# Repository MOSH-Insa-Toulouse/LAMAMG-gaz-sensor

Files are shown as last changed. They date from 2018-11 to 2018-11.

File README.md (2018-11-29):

# LAMAMG-gaz-sensor

> A Smart Gaz Sensor that just works.

[][node-red-url]
[][node-red-dashboard-url]
[][node-red-ttn-url]
[][arduino-ttn-url]

The result of our project can be seen on the following picture, which is a screenshot of our application's dashboard.

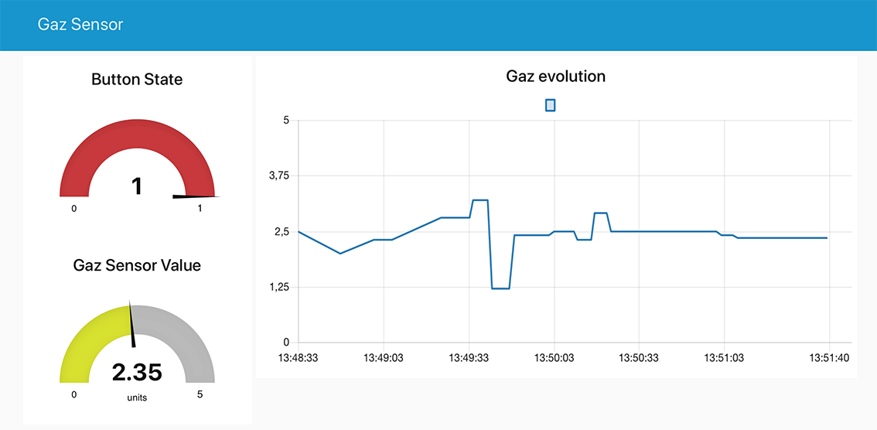
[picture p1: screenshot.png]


Our application is simple:
- we collect data through a gaz sensor connected to an Arduino board
- then, we send it to a NodeRed serving using TTN and LoRa
- once the data is received by the server, the dashboard is updated
- the values are displayed separately (two gauges for the sensor & the button state values, one chart for the evolution of the sensor value)

As of now, the button is purely decorative (it once served to send data when at '1').   

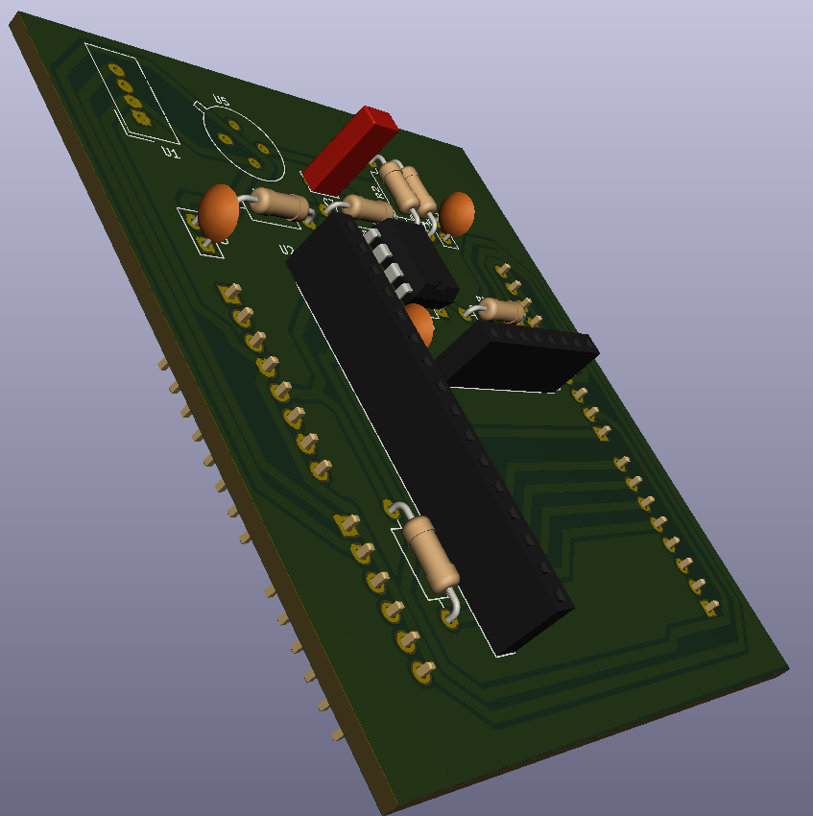
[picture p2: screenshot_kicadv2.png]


We designed our own Arduino shield using the KiCad software. It directly connects to the Arduino board used (101). 
On it, you can add the following devices:
- a Grove LCD screen (http://wiki.seeedstudio.com/Grove-LCD_RGB_Backlight)
- a Grove gaz sensor (http://wiki.seeedstudio.com/Grove-Gas_Sensor)
- our homemade gaz sensor (with an integrated AOP)
- the RN2483 LoRa transceiver module and its board (https://www.microchip.com/wwwproducts/en/RN2483) 

## Installation

OS X & Linux:

```bash
sudo apt install nodejs npm
npm install node-red node-red-ttn node-red-dashboard
cp NodeRED/flows.json ~/.node-red/flows.json
node-red &
```

Then the Dashboard will be visible on http://localhost:1880/ui, and the admin page
will be available on http://localhost:1880.

## Usage example

Power up the Arduino next to a LoRa Gateway which is using The Things Network.
Then connect to http://localhost:1880/ui on the device running Node-Red, and watch
the gauges and the graphs updated in real-time.

## Dependencies

* Node-RED
    * node-red
    * node-red-dashboard
    * node-red-contrib-ttn
* TTN - The Things Network Account
* Arduino
    * Arduino Compiler
    * The Things Network Library
    * Software Serial Library

## Development setup

### NodeRED
Follow the Instllation section, and visit the http://localhost:1880/ with your
favorite browser. You can here change the flows linked to the Dashboard.
Please update the default NodeRED flow to `~/path/to/directory/NodeRED/flows.json`
into the `~/.node-red/settings.json` file before modifying the flows.

### KiCad
The PCB has been designed on KiCad. To contribute to it, you should install it on
[here](http://kicad-pcb.org/download/).
You will then find the KiCad project into the `Kicad/shield` directory.

### Arduino code
The Arduino Code has been developped on _Arduino IDE_ which can be
downloaded [here](https://www.arduino.cc/en/Main/Software). You may need
to fix the dependencies you'll find in the Dependencies' section.
You can easily find them into the package manager of the IDE.

## Contributors
 
 | Name           | Contact                        |
 |----------------|--------------------------------|
 | Maxime Grac    | grac@etud.insa-toulouse.fr     |
 | Lucas Audibert | l_audibe@etud.insa-toulouse.fr |
 | Adrien Marty   | a_marty@etud.insa-toulouse.fr  |

Distributed under the MIT license. See ``LICENSE`` for more information.

## Contributing

1. Fork it (https://github.com/MOSH-Insa-Toulouse/LAMAMG-gaz-sensor.git)
2. Create your feature branch (`git checkout -b feature/fooBar`)
3. Commit your changes (`git commit -am 'Add some fooBar'`)
4. Push to the branch (`git push origin feature/fooBar`)
5. Create a new Pull Request

<!-- Markdown link & img dfn's -->
[node-red-image]: https://img.shields.io/badge/node--red-v0.19.5-orange.svg
[node-red-url]: https://nodered.org
[node-red-dashboard-image]: https://img.shields.io/badge/node--red--dashboard-v2.9.8-orange.svg
[node-red-dashboard-url]: https://github.com/node-red/node-red-dashboard
[node-red-ttn-image]: https://img.shields.io/badge/node--red--ttn-v2.0.4-orange.svg
[node-red-ttn-url]: https://www.npmjs.com/package/node-red-contrib-ttn
[arduino-ttn-image]: https://img.shields.io/badge/TTN_Arduino-v2.5.13-orange.svg
[arduino-ttn-url]: https://github.com/TheThingsNetwork/arduino-device-lib

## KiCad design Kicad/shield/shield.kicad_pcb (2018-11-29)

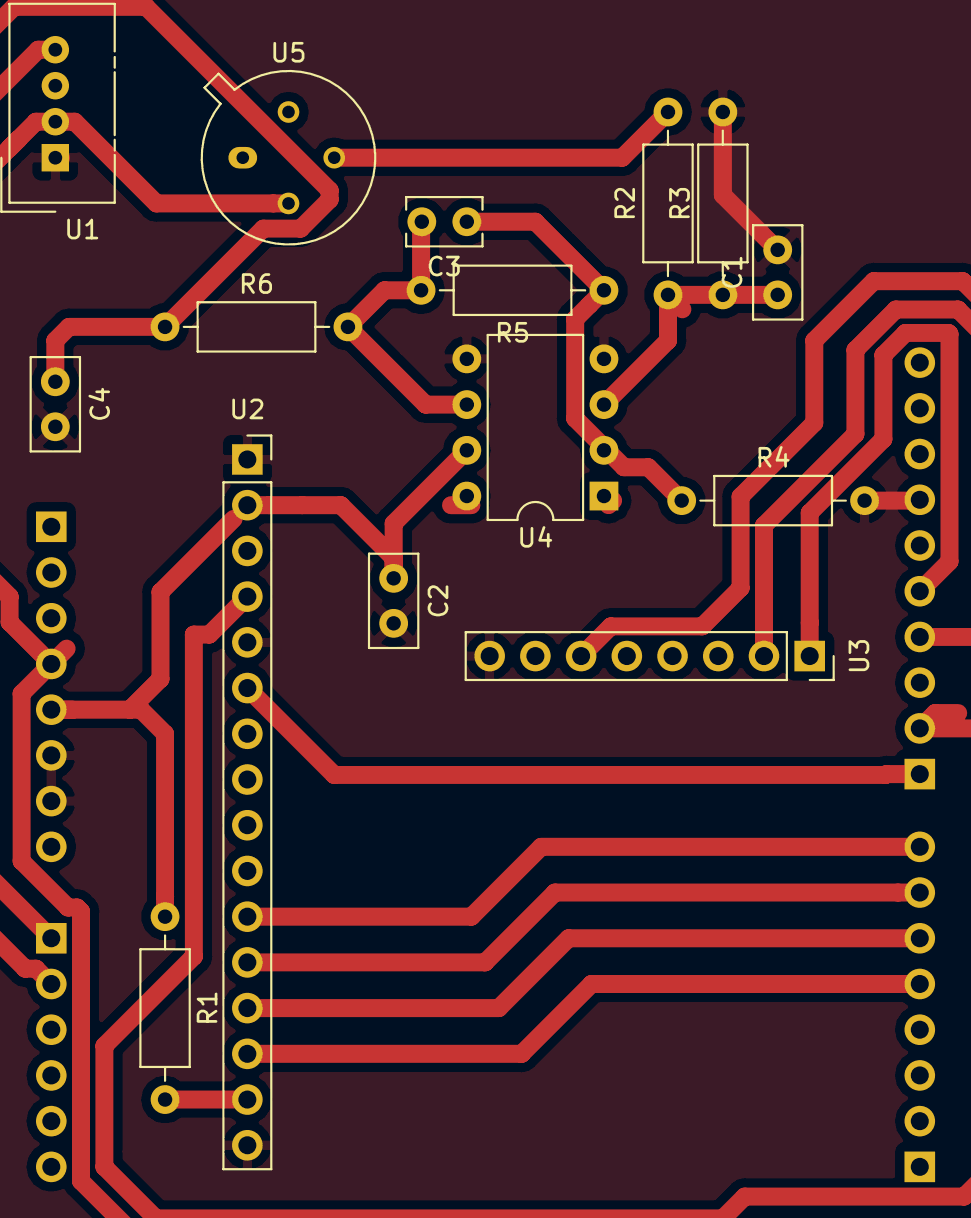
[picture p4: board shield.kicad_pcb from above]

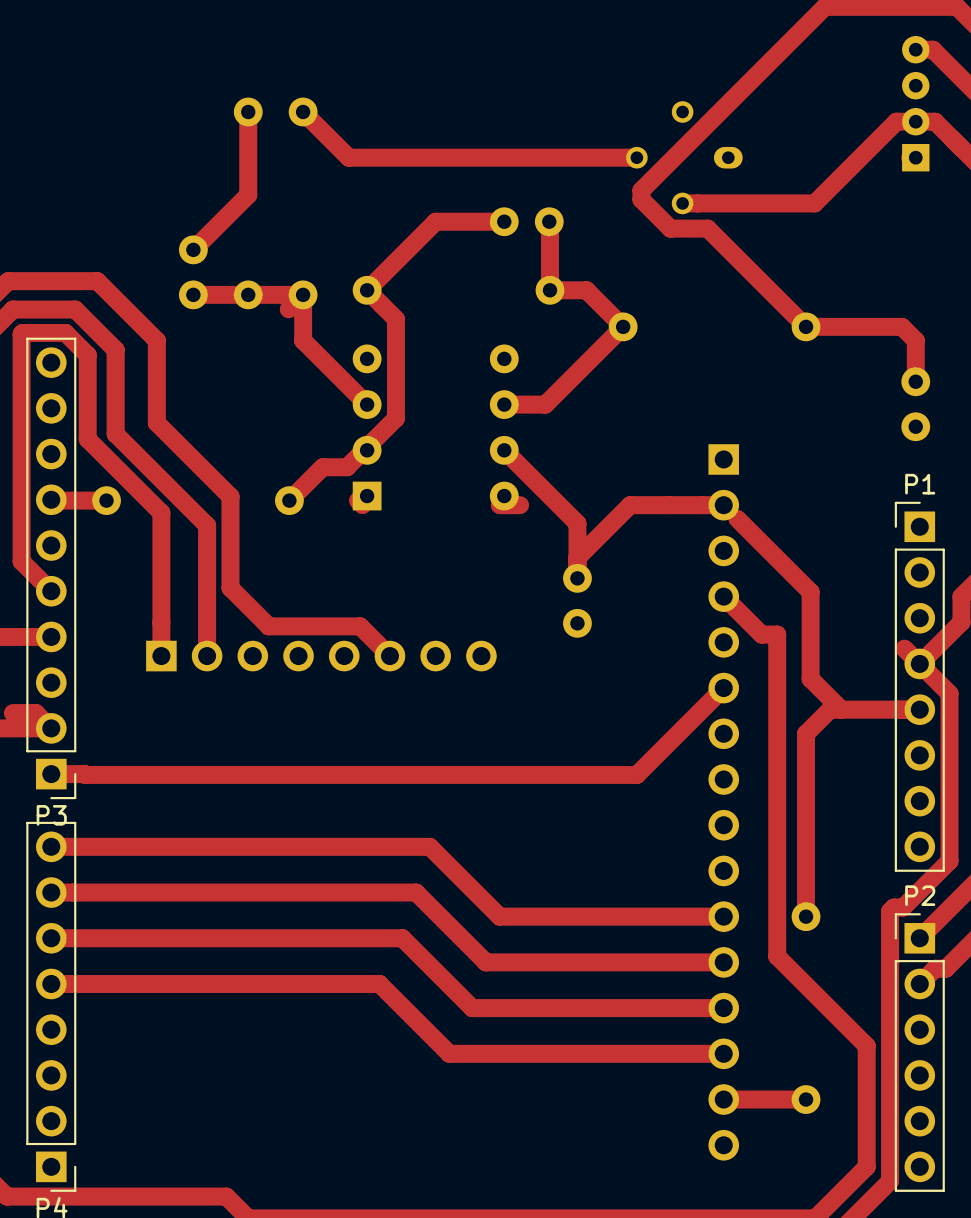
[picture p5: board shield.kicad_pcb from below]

Board: 2 copper layers, 19 parts (4 on the bottom side), 18 nets.

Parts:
C1, C2, C4: C; C_Disc_D5.0mm_W2.5mm_P2.50mm
C3: C; C_Rect_L4.0mm_W2.5mm_P2.50mm
P1, P4: CONN_01X08; PinHeader_1x08_P2.54mm_Vertical
P2: CONN_01X06; PinHeader_1x06_P2.54mm_Vertical
P3: CONN_01X10; PinHeader_1x10_P2.54mm_Vertical
R1, R2, R3, R4, R5, R6: R; R_Axial_DIN0207_L6.3mm_D2.5mm_P10.16mm_Horizontal
U1: gaz_sensor; NS-Tech_Grove_1x04_P2mm_Vertical
U2: LCD_screen; PinSocket_1x16_P2.54mm_Vertical
U3: RN2483A; PinSocket_1x08_P2.54mm_Vertical
U4: LT1050; DIP-8_W7.62mm
U5: Gaz_Sensor; TO-5-4

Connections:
+3V3: P1.4, U1.2, U3.6, U5.2
+5V: C2.1, P1.5, R1.1, U2.2, U4.7
/#D5: P4.6, U2.13
/#D6: P4.7, U2.12
/#D9: P3.2, U2.4
/#D11: P3.4, U3.2
/A0: P2.1, U1.4
/A1: C4.1, P2.2, R6.1
/D4: P4.5, U2.14
/D7: P4.8, U2.11
/D8: P3.1, U2.6
/D12: P3.5, U3.1
/Isens: R2.2, U5.3
GND: C1.2, C2.2, C4.2, P1.6, P1.7, P3.7, R3.2, R4.2, U1.1, U2.1, U2.5, U2.16, U3.8, U4.4, U4.5
unnamed: C1.1, R2.1, R3.1, U4.3
unnamed: C3.1, R4.1, R5.1, U4.2
unnamed: C3.2, R5.2, R6.2, U4.6
unnamed: R1.2, U2.15

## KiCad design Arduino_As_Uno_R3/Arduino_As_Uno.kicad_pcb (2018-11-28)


Board: 2 copper layers, 68.6 x 53.3 mm, 8 parts (0 on the bottom side), 3 nets, no tracks yet.

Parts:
P1: Power; Socket_Strip_Arduino_1x08
P2: Analog; Socket_Strip_Arduino_1x06
P3: Digital; Socket_Strip_Arduino_1x10
P4: Digital; Socket_Strip_Arduino_1x08
P5, P6, P7, P8: CONN_01X01; Arduino_1pin

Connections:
/A4(SDA): P2.5, P3.2
/A5(SCL): P2.6, P3.1
GND: P1.6, P1.7, P3.4

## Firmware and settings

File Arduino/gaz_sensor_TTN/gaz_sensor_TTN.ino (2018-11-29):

#include <LiquidCrystal.h>
#include <TheThingsNetwork.h>
#include <SoftwareSerial.h>

// Creating a software serial
SoftwareSerial loraSerial(8,9);
#define debugSerial Serial

// Variables' declaration
float sensor_volt = 0;
int LED = 13;
volatile byte state = LOW;
LiquidCrystal myScreen(12,11,7,6,5,4); // creating the screen object

// Data needed to connect to the TTN 
const char *devAddr = "26011078";
const char *nwkSKey = "E63AE401DD3BA8C23DA9670B93455FF3";
const char *appSKey = "B28065B3C01B31621D5D0DED68B16511";

TheThingsNetwork ttn(loraSerial, debugSerial, TTN_FP_EU868);

void setup() {
  // Setting up the serial ports
  loraSerial.begin(57600);
  debugSerial.begin(9600);

  // Asking for the TTN status
  debugSerial.println("-- STATUS");
  ttn.showStatus();

  // Configuring the TTN
  debugSerial.println("-- PERSONALIZE");
  ttn.personalize(devAddr, nwkSKey, appSKey);
  ttn.personalize();
  debugSerial.println("-- PERSONALIZED");

  // Configuring the LED
  pinMode(LED,OUTPUT);
  pinMode(2,INPUT_PULLUP);
  digitalWrite(LED, LOW);

  // Initializing the LCD screen
  myScreen.begin(16,2);
  myScreen.clear();
  myScreen.print("Gaz Sensor");
  myScreen.setCursor(0, 1);

  // Creating a payload to be sent to the TTN
  byte payload[1];
  payload[0] = (digitalRead(2) == HIGH) ? 1 : 0;
  ttn.sendBytes(payload, sizeof(payload));
}

void loop() {
  // Displaying the analog value of the sensor on the LCD screen
  sensor_volt = analogRead(A0)/1024.0*5.0;
  myScreen.setCursor(0, 1);
  myScreen.print(sensor_volt);

  // Sending the payload to the TTN
  byte payload[2];
  payload[0] = (digitalRead(2) == HIGH) ? 1 : 0;
  payload[1] = 100*sensor_volt;
  ttn.sendBytes(payload, sizeof(payload));
  
  delay(5000);
}

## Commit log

2018-10-09 First commit Arduino
2018-10-16 Ajout Kicad
    [shield.kicad_pcb, shield.sch]
2018-10-16 Add Node-Red flow for Dashboard
2018-10-16 Ajout elements
    [shield.sch]
2018-10-18 Creation PCB
    [Arduino_As_Uno.kicad_pcb, Arduino_As_Uno.sch, Pinout.sch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]
2018-11-29 récupération des fichiers KiCad
    [Pinout.sch, shield.kicad_pcb, shield.sch]
2018-11-29 Resolving connection problems between grounds
2018-11-29 Fix no saving
    [shield.kicad_pcb]
2018-11-29 Modification du screenshot 3D KiCad
2018-11-29 Ajout de commentaires dans le code arduino
